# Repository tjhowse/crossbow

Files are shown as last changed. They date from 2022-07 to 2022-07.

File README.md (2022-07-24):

# Laser cut crossbow.

This is a project to make a toy crossbow out of plywood on a laser cutter.

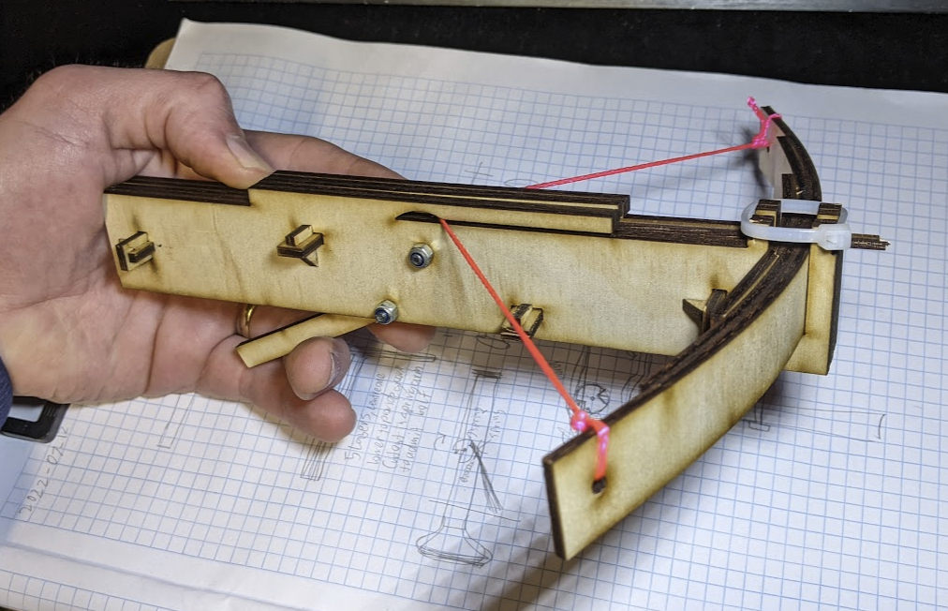
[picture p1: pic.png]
Laser cut wooden crossbow


## Videos

https://www.youtube.com/watch?v=S2TYj92p1cU

https://www.youtube.com/watch?v=FJKkn_zltdg

## Project status

The design is finished, but there is some scope for improvement:

* Wood-based alternative to the trigger and sear pivot points,
* Cosmetics.

## Building

The design is highly sensitive to the thickness of the plywood used. Measure
your ply and plug the dimension (in mm) to the body_ply_thickness variable
to ensure everything's nice and snug. There are DXFs in this repo for 2.85mm
and 3mm ply.

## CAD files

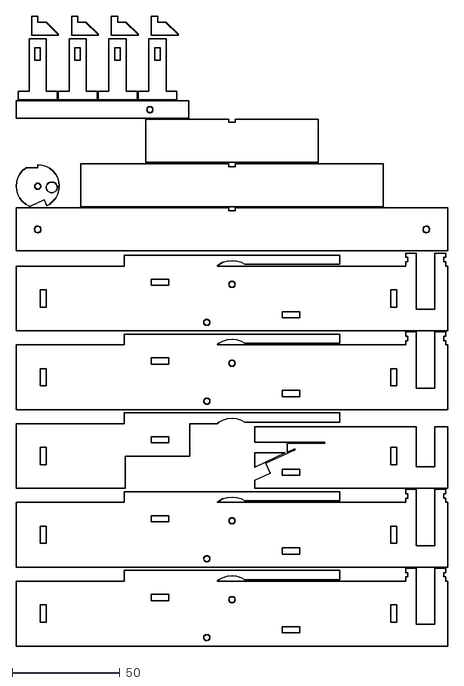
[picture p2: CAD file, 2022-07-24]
crossbow_2.85mm_ply.dxf
200.0 x 291.9

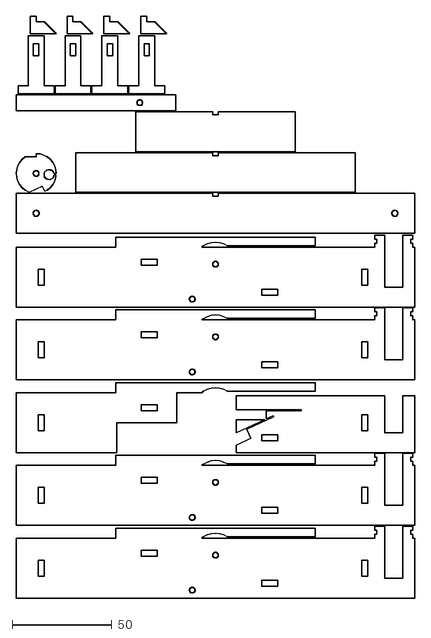
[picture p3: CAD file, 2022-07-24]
crossbow_3mm_ply.dxf
200.0 x 292.0

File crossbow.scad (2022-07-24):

// This is a design for a laser-cut plywood crossbow.
// Author: Travis Howse (tjhowse@gmail.com)
// Website: https://github.com/tjhowse/crossbow
// License: CC-0 1.0
// It was built in OpenSCAD 2015.03-2. It's very old, I know, I'm lazy.
// I'm not doing anything too funky, it should work fine in newer versions.

// Z-fight fudge. Tweak dimensions this much to avoid z-fighting in the rendering.
// This does not consequentially affect the dimensions physical product.
zff = 0.01;
// This sets the render output for all the pieces laid out. Set from the makefile.
full_render = false;
// How many facets on the circles.
$fn = 32;
// Length of body
body_length = 200;
// Height of body
body_height = 30;
// The thickness of each layer of the body's plywood
body_ply_thickness = 2.85;
// How many layers of plywood laminated into the body. This must be an odd number.
body_layers = 5;
if (body_layers%2 != 1) {
    echo("body_layers must be an odd number.");
}
// The overall thickness of the body.
body_thickness = body_ply_thickness * body_layers;
// This is the thickness of the part of the body that wraps around the bow to hold it in place.
body_bow_retain = 6;


// Radius of the bolt fired from this crossbow. Must be less than half the material thickness of the body.
bolt_r = body_ply_thickness/2;
// This is the length of the bolt.
bolt_length = 100;

// The radius of the cord.
cord_r = 0.75;
// The radius of the sear wheel.
sear_r = 10;
// The depth of the cutout into the sear that engages with the trigger arm.
sear_trigger_notch = 3;
// The angle the trigger arm makes to the sear.
sear_trigger_angle = 25;
// The radius of the shaft through the sear.
sear_shaft_r = 2.8/2;
// This is the clearance between the sear and the body
sear_body_clearance = 0.5;

// The number of layers of plywood forming the bow.
bow_layers = 3;
// The thickness of each layer of plywood forming the bow.
bow_ply_thickness = body_ply_thickness;
// The left-to-right length of the bow when assembled.
bow_length = 200;
// The height of the bow. This shouldn't be more than half the body_height.
bow_height = 20;
// The reduction in length of each layer of the bow as a proportion of the length,
// per layer. Think of a leaf spring.
bow_leaf_ratio = 0.3;
// This is the distance between the end of the bow and the cord hole.
bow_cord_tie_offset = 10;
// This is the overall thickness of the bow at its thickest point.
bow_thickness = bow_ply_thickness * bow_layers;

// This is the offset between the sear and body origins
sear_body_offset = [body_length - bolt_length, body_height - sear_r + cord_r*2, floor(body_layers/2)*body_ply_thickness];
// This is the offset between the bow and body origins
bow_body_offset = [body_length-body_bow_retain,body_height-bow_height,body_thickness/2];

// This is the overall length of the trigger.
trigger_length = 80;
// This is the height of the trigger.
trigger_height = 8;
// This is the thickness of the ply used for the trigger.
trigger_ply_thickness = body_ply_thickness;
// This is the offset between the trigger and sear module origins.
trigger_sear_offset = [trigger_length,trigger_height+sear_r-sear_trigger_notch,0];
// This is the distance from the sear end of the trigger for the trigger rotation shaft.
trigger_shaft_distance_from_sear_end = 18;
// This is the offset between the origin of the trigger module and its shaft.
trigger_shaft_offset = [trigger_length-trigger_shaft_distance_from_sear_end, trigger_height/2,0];
// This is the radius of the shaft for the trigger.
trigger_shaft_r = sear_shaft_r;

// This is the gap left between parts laid out for laser cutting.
laser_clearance = 0.5;

// This is the thickness and width of the spring material, made from a windscreen wiper blade insert.
// This material is used for the sear and trigger springs.
spring_clearance = -0.2;
spring_thickness = 0.778+spring_clearance;
spring_width = 2.5;

// This is the length of the sear spring.
sear_spring_length = 30;
trigger_spring_length = 30;

// This is the depth of the cutout in the sear to engage with the sear spring.
sear_spring_sear_cutout_depth = sear_r/2;
// This is the height of the cutout in the sear to engage with the sear spring.
sear_spring_sear_cutout_height = spring_thickness;
// This is the width of the cutout in the body to let the sear spring flex downards
sear_spring_body_cutout_width = sear_spring_length/2;
// This is the height of the cutout in the body to let the sear spring flex downards
sear_spring_body_cutout_height = sear_spring_sear_cutout_depth;
// This is how much the sear spring engages with the sear at rest. This number is not very scientific.
sear_spring_engagement_distance = sear_spring_sear_cutout_depth/2;
sear_spring_edge = 1;
sear_spring_cutout_void_r = 2.5;

// This is how much the trigger spring engages with the trigger at rest. This number is not very scientific.
trigger_spring_engagement_distance = 5;
// This is the width of the cutout in the body that lets the trigger spring flex downwards.
trigger_spring_body_cutout_width = trigger_spring_length/3;
// This is the height of the cutout in the body that lets the trigger spring flex downwards.
trigger_spring_body_cutout_height = body_height/6;


// This is the height, or thickness, of the overarm that holds the bolt in place.
overarm_height = 5;
// This is the overall length of the overarm.
overarm_length = body_length/2;
// This is the vector from the overarm origin to the body origin.
overarm_body_offset = [body_length-bolt_length/2-overarm_length,body_height,0];
// This is the clearance between the overarm and the sear.
overarm_sear_clearance = 1;

// This is the rotating mechanism that engages with the cord and the trigger arm to retain
// the cord tension until the trigger is squeezed.
module sear() {
    difference() {
        // The main body of the sear.
        cylinder(r=sear_r, h=body_ply_thickness);
        // The cutout that engages with the cord.
        translate([-100, sear_r-cord_r*2,-zff]) cube([100,cord_r*2, body_ply_thickness+2*zff]);
        // The cutout that engages with the trigger arm.
        rotate([0,0,sear_trigger_angle])
            translate([-100, -sear_r,-zff])
                cube([100,sear_trigger_notch, body_ply_thickness+2*zff]);
        // The hole through the centre of the sear through which the shaft passes to secure the sear inside the body.
        cylinder(r=sear_shaft_r, h=body_ply_thickness);
        // This is a cutout in the sear to engage with the spring.
        translate([sear_r-sear_spring_sear_cutout_depth,-sear_spring_sear_cutout_height,0]) union() {
            cube([sear_spring_sear_cutout_depth,sear_spring_sear_cutout_height,body_ply_thickness]);
            translate([sear_r/2-sear_spring_cutout_void_r-sear_spring_edge,0,0]) cylinder(r=sear_spring_cutout_void_r, h=body_ply_thickness);
        }
    }

}

// This is the length of the cutout section around the trigger and sear mechanism.
mechanism_cutout_x = 60;

// This is the thickness of the ply used for the pins through the body.
body_pin_ply_thickness = body_ply_thickness;
// This is the extra width to the pin to form the head.
body_pin_head_flange_x = 5;
// This is the extra width to the pin to form the head.
body_pin_head_flange_y = 4;
// This is the width of the body pin.
body_pin_width = 8;
// This is the length of the slot in the end of the body pin to allow the body cross pin through.
body_pin_slot_length = 6;
// This is the extra length of the body pin past the cross pin slot.
body_pin_past_slot = body_pin_head_flange_y;
// This is the length of the cross pin that holds the body pin in place.
body_cross_pin_length = body_ply_thickness*3;
// This is an extra little bit of length to the body cross pin to give it more flat
// surface to engage with the body pin before the taper starts.
body_cross_pin_extra_flat = 1;
// This makes the cross pin slightly tighter.
body_cross_pin_clearance = -0.3;

// This is the width of the ziptie post used to clamp the bow in place
body_ziptie_post_width = 5;
// This is the width
body_ziptie_post_height = 6;
// This is the height of the notch to position the ziptie.
body_ziptie_post_notch_height = 2;
// This is the depth of the ziptie notch.
body_ziptie_post_notch_width = 1;
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

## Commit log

2022-07-12 Typing typing
    [crossbow.scad]
2022-07-13 Slicing into layer, trigger, bow shrinkage, lots.
    [crossbow.scad]
2022-07-13 Make it smaller, fix some bad parametricness.
    [crossbow.scad]
2022-07-13 Comments, tweaks.
    [crossbow.scad]
2022-07-14 Add pins, made video.
    [crossbow.scad, crossbow_3mm_ply.dxf]
2022-07-14 Link bow ply thickness to body ply thickness.
    [crossbow.scad]
2022-07-16 Minor dimension tweaks.
    [crossbow.scad]
2022-07-16 Add overarm and sear/trigger springs.
    [crossbow.scad, crossbow_2.85mm_ply.dxf]
2022-07-16 Improve docs, automate build, improve spring mechanism.
    [crossbow.scad, crossbow_2.85mm_ply.dxf, crossbow_3mm_ply.dxf]
2022-07-16 Fix up some TODOs.
    [crossbow.scad]
2022-07-24 Link to new video.
    [crossbow.scad, crossbow_2.85mm_ply.dxf, crossbow_3mm_ply.dxf]
